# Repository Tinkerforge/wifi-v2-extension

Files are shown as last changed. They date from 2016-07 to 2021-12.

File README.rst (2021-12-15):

WIFI Extension 2.0
==================

This repository contains the hardware design files.
The software is included in the Master Brick software
and can be found at https://github.com/Tinkerforge/master-brick

Repository Content
------------------

hardware/:
 * Contains KiCad project files and additionally schematics as PDF

datasheets/:
 * Contains datasheets for sensors and complex ICs that are used

Hardware
--------

The hardware is designed with the open source EDA Suite KiCad
(http://www.kicad.org). Before you are able to open the files,
you have to install the Tinkerforge kicad-libraries
(https://github.com/Tinkerforge/kicad-libraries). You can either clone
them directly in hardware/ or clone them in a separate folder and
symlink them into hardware/
(ln -s kicad_path/kicad-libraries project_path/hardware). After that you
can open the .pro file in hardware/ with KiCad and from there view and
modify the schematics and the PCB layout.

Toolchain
---------

Clone and build toolchain from https://github.com/pfalcon/esp-open-sdk
into toolchain/ directory. The following instructions apply for ESP8266 SDK 1.5.3::

 sudo apt-get install build-essential gperf libtool libtool-bin help2man texinfo libncurses5-dev python2.7-dev autoconf
 mkdir toolchain
 cd toolchain
 git clone --recursive https://github.com/Tinkerforge/esp-open-sdk.git
 cd esp-open-sdk
 make STANDALONE=y VENDOR_SDK=1.5.3

Update toolchain::

 make clean
 git pull
 git submodule sync
 git submodule update
 make STANDALONE=y VENDOR_SDK=1.5.3

Additionally we use libesphttpd::

 cd toolchain
 git clone --recursive http://git.spritesserver.nl/libesphttpd.git/

To be able to build the extension firmware using libesphttpd a patch must be
applied to the ESP8266 SDK. This assumes that the toolchain is already
successfully built::

 cd software
 patch -b -N -d ../toolchain/esp-open-sdk/sdk/include -p1 < esp8266sdk-c_types.patch

libesphttpd must also be patched::

 cd software
 patch -b -N -d ../toolchain/libesphttpd -p1 < libesphttpd-Makefile.patch
 patch -b -N -d ../toolchain/libesphttpd -p1 < libesphttpd-httpd-nonos.patch

Build
-----

Provided that all the steps of the toolchain section was followed properly the
extension firmware can be built with::

 cd software
 make clean
 make

The compiled firmware can be found here::

 software/firmware/wifi_extension_v2_firmware.zbin

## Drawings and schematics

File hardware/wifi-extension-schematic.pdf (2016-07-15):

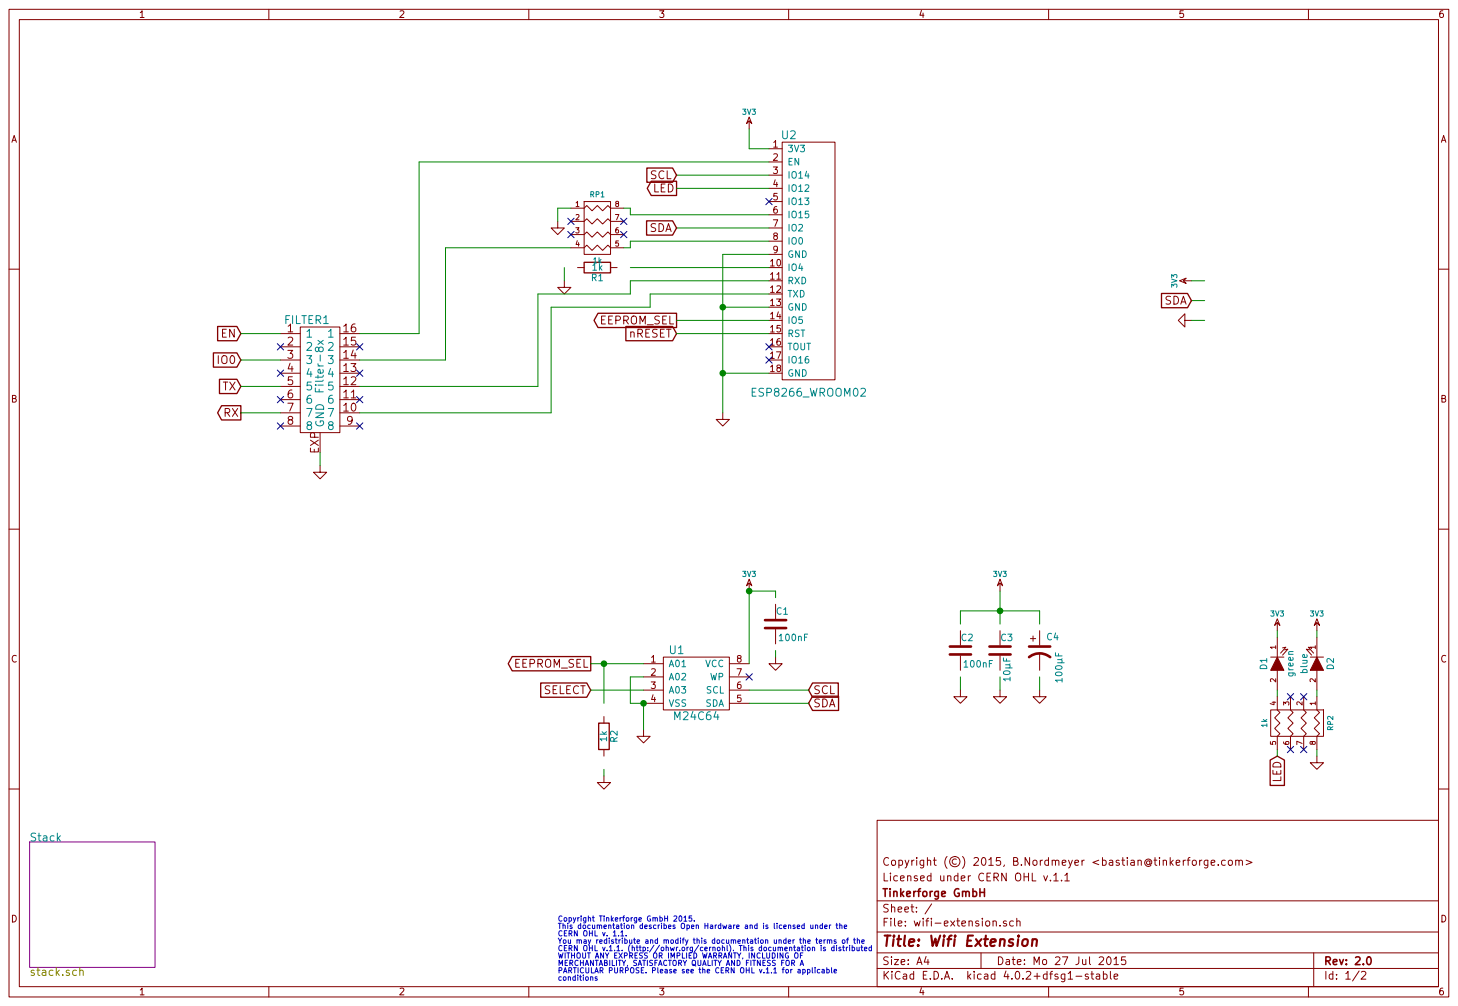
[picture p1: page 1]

File: wifi-extension.sch Sheet: / Tinkerforge GmbH

Copyright Tinkerforge GmbH 2015. This documentation describes Open Hardware and is licensed under the CERN OHL v. 1.1. You may redistribute and modify this documentation under the terms of the CERN OHL v.1.1. (http://ohwr.org/cernohl). This documentation is distributed WITHOUT ANY EXPRESS OR IMPLIED WARRANTY, INCLUDING OF MERCHANTABILITY, SATISFACTORY QUALITY AND FITNESS FOR A

Id: 1/2 Title: Wifi Extension

PARTICULAR PURPOSE. Please see the CERN OHL v.1.1 for applicable
conditions

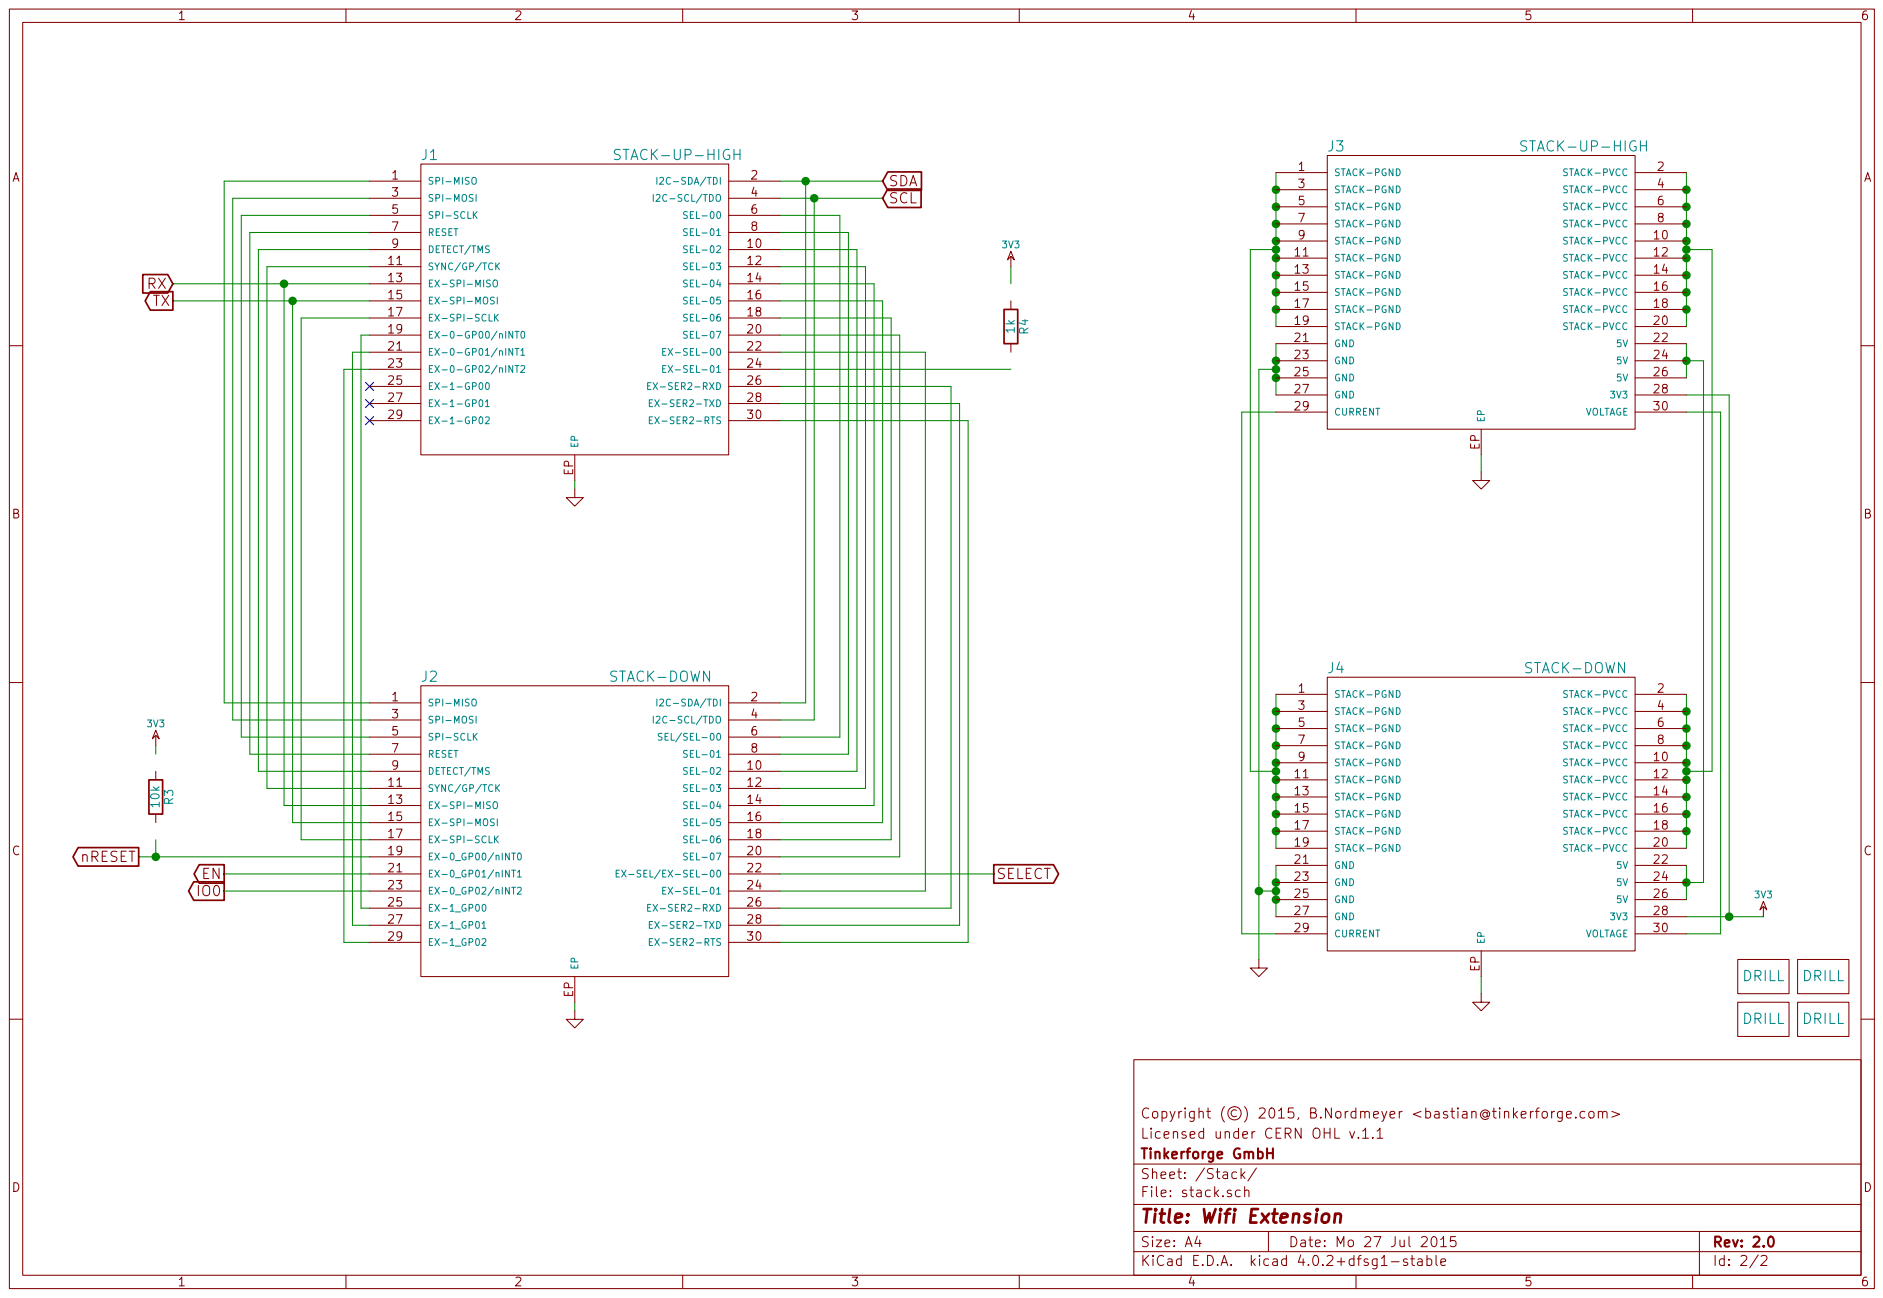
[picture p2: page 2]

SPI-MOSI 3
SPI-SCLK 5

Licensed under CERN OHL v.1.1 Copyright (©) 2015, B.Nordmeyer <bastian@tinkerforge.com> EN

File: stack.sch Sheet: /Stack/ Tinkerforge GmbH

Id: 2/2 Title: Wifi Extension

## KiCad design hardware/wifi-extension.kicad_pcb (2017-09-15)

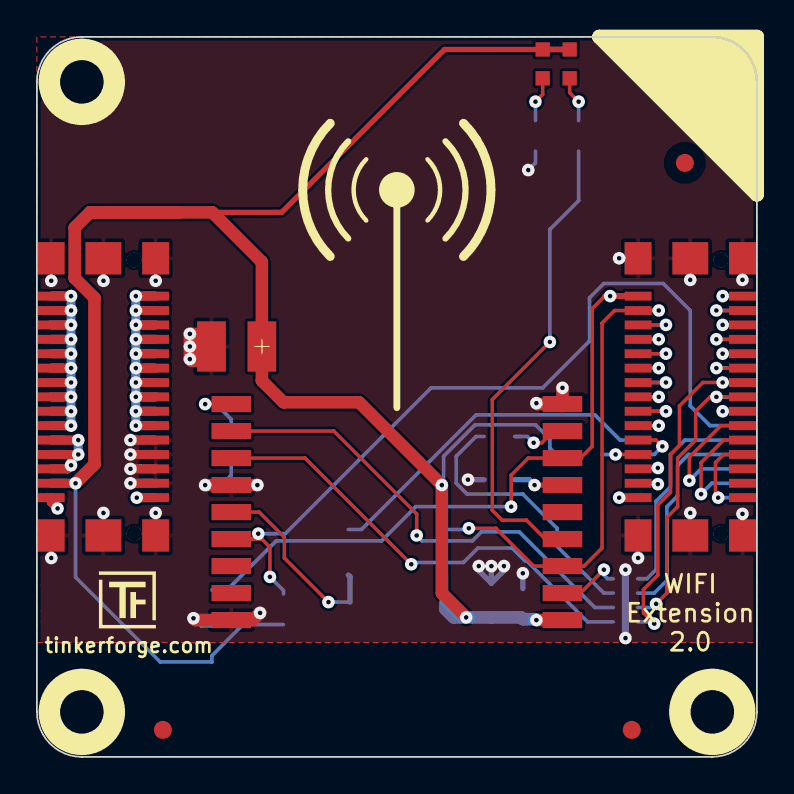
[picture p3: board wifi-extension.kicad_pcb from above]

Board: 2 copper layers, 40.0 x 40.0 mm, 34 parts (0 on the bottom side), 49 nets.

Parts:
C1, C2: 100nF; C0603E
C3: 10µF; C0805E
C4: 100µF; 3528-21
D1: green; D0603
D2: blue; D0603
FILTER1: Filter-8x; DFN16-33x135
Fiducial_Mark: VAL**; Fiducial_Mark
Fiducial_Mark#2, Fiducial_Mark#3, Fiducial_Mark#4, Fiducial_Mark#5, Fiducial_Mark#6: VAL**; Fiducial_Mark
J1, J3: STACK-UP-HIGH; BTB08-ACS-TOP
J2, J4: STACK-DOWN; BTB08-ACS-BTM
P1, P2, P3: CONN_1; TSTPT
R1, R2, R4: 1k; R0603E
R3: 10k; R0603E
RP1, RP2: 1k; 0603X4
U1: M24C64; SOIC8
U2: ESP8266_WROOM02
U3, U4, U5, U6: DRILL; DRILL_NP
VAL: CE_5mm
VAL#2: WEEE_7mm_back

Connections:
3V3: C1.2, C2.2, C3.2, C4.1, D1.1, D2.1, J3.28, J4.28, P1.1, R3.1, R4.1, U1.8, U2.1
EEPROM_SEL: R2.1, U1.1, U2.14
EN: FILTER1.1, J2.21
GND: C1.1, C2.1, C3.1, C4.2, FILTER1.EXP, J1.EP, J2.EP, J3.21, J3.23, J3.25, J3.27, J3.EP, J4.21, J4.23, J4.25, J4.27, J4.EP, P3.1, R1.2, R2.2, RP1.1, RP2.8, U1.2, U1.4, U2.9, U2.13, U2.18
IO0: FILTER1.3, J2.23
LED: RP2.5, U2.4
unnamed: D1.2, RP2.4
unnamed: D2.2, RP2.1
unnamed: FILTER1.10, U2.12
unnamed: FILTER1.12, U2.11
unnamed: FILTER1.14, RP1.4
unnamed: FILTER1.16, U2.2
unnamed: J1.1, J2.1
unnamed: J1.3, J2.3
unnamed: J1.5, J2.5
unnamed: J1.6, J2.6
unnamed: J1.7, J2.7
unnamed: J1.8, J2.8
unnamed: J1.9, J2.9
unnamed: J1.10, J2.10
unnamed: J1.11, J2.11
unnamed: J1.12, J2.12
unnamed: J1.14, J2.14
unnamed: J1.16, J2.16
unnamed: J1.17, J2.17
unnamed: J1.18, J2.18
unnamed: J1.19, J2.25
unnamed: J1.20, J2.20
unnamed: J1.21, J2.27
unnamed: J1.22, J2.24
unnamed: J1.23, J2.29
unnamed: J1.24, R4.2
unnamed: J1.26, J2.26
unnamed: J1.28, J2.28
unnamed: J1.30, J2.30
unnamed: J3.1, J3.3, J3.5, J3.7, J3.9, J3.11, J3.13, J3.15, J3.17, J3.19, J4.1, J4.3, J4.5, J4.7, J4.9, J4.11, J4.13, J4.15, J4.17, J4.19
unnamed: J3.2, J3.4, J3.6, J3.8, J3.10, J3.12, J3.14, J3.16, J3.18, J3.20, J4.2, J4.4, J4.6, J4.8, J4.10, J4.12, J4.14, J4.16, J4.18, J4.20
unnamed: J3.22, J3.24, J3.26, J4.22, J4.24, J4.26
unnamed: J3.29, J4.29
unnamed: J3.30, J4.30
unnamed: R1.1, U2.10
unnamed: RP1.5, U2.8
unnamed: RP1.8, U2.6
RX: FILTER1.7, J1.13, J2.13
SCL: J1.4, J2.4, U1.6, U2.3
SDA: J1.2, J2.2, P2.1, U1.5, U2.7
SELECT: J2.22, U1.3
TX: FILTER1.5, J1.15, J2.15
nRESET: J2.19, R3.2, U2.15

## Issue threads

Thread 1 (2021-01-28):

Status LED does not turn back on, when manually turned off and back on

PatrickBaus, 2021-01-28:
Hi,

I am working with the WIFI 2.0 extension and during testing I found what seems to be a bug in the status led handling.

When the wifi module is in client mode the green status led is lit, when connected. Now if I turn is off using the [BrickMaster.disable_wifi2_status_led()](https://www.tinkerforge.com/en/doc/Software/Bricks/Master_Brick_Python.html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) call it turn off as it is supposed to, but when I enable the led using [BrickMaster.enable_wifi2_status_led()](https://www.tinkerforge.com/en/doc/Software/Bricks/Master_Brick_Python.html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), it will stay off. I glanced at the source code and if you run [enable_wifi2_status_led()](https://www.tinkerforge.com/en/doc/Software/Bricks/Master_Brick_Python.html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)/FunctionID 99, the wifi extensions seems to register with some event system. So if there is no new event, the led will stay off.

**Expected behaviour**: The led turns back on
**As is**: The led is only turned back on, if there is an internal event, that switches the led.
**Master firmware**: 2.4.10
**WIFI 2.0 firmware**: 2.1.4

Closed 2021-12-15.

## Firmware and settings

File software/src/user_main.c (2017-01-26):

/* WIFI Extension 2.0
 * Copyright (C) 2015 Olaf Lüke <olaf@tinkerforge.com>
 * Copyright (C) 2016 Ishraq Ibne Ashraf <ishraq@tinkerforge.com>
 *
 * user_main.c: Handling of communication between PC and WIFI Extension
 *
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
 * You should have received a copy of the GNU Lesser General Public
 * License along with this library; if not, write to the
 * Free Software Foundation, Inc., 59 Temple Place - Suite 330,
 * Boston, MA 02111-1307, USA.
 */

#include "espmissingincludes.h"
#include "osapi.h"
#include "gpio.h"
#include "user_interface.h"
#include "drivers/uart.h"
#include "tfp_connection.h"
#include "http_connection.h"
#include "tfp_websocket_connection.h"
#include "uart_connection.h"
#include "debug.h"
#include "i2c_master.h"
#include "eeprom.h"
#include "logging.h"
#include "configuration.h"
#include "espconn.h"
#include "ringbuffer.h"
#include <string.h>
#include <esp8266.h>

extern Ringbuffer tfp_rb;
extern Configuration configuration_current;
extern Configuration configuration_current_to_save;
extern uint8_t tfp_rb_buffer[TFP_RING_BUFFER_SIZE];

void ICACHE_FLASH_ATTR user_init_done_cb(void) {
	char str_fw_version[4];

	os_bzero(str_fw_version, sizeof(str_fw_version));
	configuration_apply_post_init();

	if(!configuration_current.mesh_enable) {
		tfp_open_connection();
		tfpw_open_connection();

		os_sprintf(str_fw_version, "%d%d%d", FIRMWARE_VERSION_MAJOR, FIRMWARE_VERSION_MINOR,
			FIRMWARE_VERSION_REVISION);

		if(strtoul(str_fw_version, NULL, 10) >= 204) {
			if(configuration_current.general_website == 1) {
				http_open_connection();
			}
		}
		else {
			if(configuration_current.general_website_port > 1) {
				http_open_connection();
			}
		}
	}
}

void ICACHE_FLASH_ATTR user_init() {
	#ifdef DEBUG_ENABLED
		debug_enable(UART_DEBUG);
	#else
		system_set_os_print(0);
	#endif

	logd("user_init()\n");

	gpio_init();

	wifi_status_led_install(12, PERIPHS_IO_MUX_MTDI_U, FUNC_GPIO12);

	#ifdef DEBUG_ENABLED
		configuration_use_default();
	#else
		i2c_master_init();
		eeprom_init();
		configuration_load_from_eeprom();
	#endif

	// The documentation says we can not call station_connect and similar
	// in user_init, so we do it in the callback after it is done!
	configuration_apply_during_init();

	// We want to make UART communication to the master of the stack ready ASAP.
	ringbuffer_init(&tfp_rb, tfp_rb_buffer, TFP_RING_BUFFER_SIZE);
	uart_con_init();
	brickd_init();
	com_init();

	os_bzero(&configuration_current_to_save, sizeof(configuration_current));
	os_memcpy(&configuration_current_to_save, &configuration_current, sizeof(configuration_current));

	system_init_done_cb(user_init_done_cb);
}

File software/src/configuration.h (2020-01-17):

/* WIFI Extension 2.0
 * Copyright (C) 2015 Olaf Lüke <olaf@tinkerforge.com>
 * Copyright (C) 2016 Ishraq Ibne Ashraf <ishraq@tinkerforge.com>
 * Copyright (C) 2020 Matthias Bolte <matthias@tinkerforge.com>
 *
 * configuration.h: WIFI Extension configuration handling
 *
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
 * You should have received a copy of the GNU Lesser General Public
 * License along with this library; if not, write to the
 * Free Software Foundation, Inc., 59 Temple Place - Suite 330,
 * Boston, MA 02111-1307, USA.
 */

#ifndef CONFIGURATION_H
#define CONFIGURATION_H

#include "config.h"
#include "c_types.h"
#include "mesh.h"

#define CONFIGURATION_EXPECTED_VERSION 2

#define CONFIGURATION_ADDRESS 32

#define CONFIGURATION_SECRET_MAX_LENGTH 64
#define CONFIGURATION_HOSTNAME_MAX_LENGTH 32
#define CONFIGURATION_PASSWORD_MAX_LENGTH 64
#define CONFIGURATION_SSID_MAX_LENGTH 32
#define CONFIGURATION_AP_PASSWORD_MIN_LENGTH 8

typedef struct {
	// Configuration info
	uint8_t  conf_checksum;
	uint8_t  conf_version;
	uint16_t conf_length;

	// General configuration
	uint16_t general_port;
	uint16_t general_websocket_port;
	uint16_t general_website_port;
	uint8_t  general_phy_mode;
	uint8_t  general_sleep_mode;
	uint8_t  general_website;
	char     general_authentication_secret[CONFIGURATION_SECRET_MAX_LENGTH]; // might not be NULL-terminated

	// Client configuration
	bool     client_enable;
	char     client_ssid[CONFIGURATION_SSID_MAX_LENGTH]; // might not be NULL-terminated
	uint8_t  client_ip[4];
	uint8_t  client_subnet_mask[4];
	uint8_t  client_gateway[4];
	uint8_t  client_mac_address[6];
	uint8_t  client_bssid[6];
	char     client_hostname[CONFIGURATION_HOSTNAME_MAX_LENGTH]; // might not be NULL-terminated
	char     client_password[CONFIGURATION_PASSWORD_MAX_LENGTH]; // might not be NULL-terminated

	// AP configuration
	bool     ap_enable;
	char     ap_ssid[CONFIGURATION_SSID_MAX_LENGTH]; // might not be NULL-terminated
	uint8_t  ap_ip[4];
	uint8_t  ap_subnet_mask[4];
	uint8_t  ap_gateway[4];
	uint8_t  ap_encryption;
	bool     ap_hidden;
	uint8_t  ap_mac_address[6];
	uint8_t  ap_channel;
	char     ap_hostname[CONFIGURATION_HOSTNAME_MAX_LENGTH]; // might not be NULL-terminated
	char     ap_password[CONFIGURATION_PASSWORD_MAX_LENGTH]; // might not be NULL-terminated

	// Mesh configuration
	bool     mesh_enable;
	char     mesh_router_ssid[CONFIGURATION_SSID_MAX_LENGTH]; // might not be NULL-terminated
	char     mesh_router_password[CONFIGURATION_PASSWORD_MAX_LENGTH]; // might not be NULL-terminated
	uint8_t  mesh_root_ip[4];
	uint8_t  mesh_root_subnet_mask[4];
	uint8_t  mesh_root_gateway[4];
	uint8_t  mesh_router_bssid[6];
	char     mesh_group_ssid_prefix[(CONFIGURATION_SSID_MAX_LENGTH / 2)]; // might not be NULL-terminated
	char     mesh_password[CONFIGURATION_PASSWORD_MAX_LENGTH]; // might not be NULL-terminated
	uint8_t  mesh_group_id[ESP_MESH_GROUP_ID_LEN];
	char     mesh_gateway_hostname[32]; // Currently unused.
	uint8_t  mesh_gateway_ip[4];
	uint16_t mesh_gateway_port;
} Configuration;

void ICACHE_FLASH_ATTR configuration_use_default(void);
void ICACHE_FLASH_ATTR configuration_load_from_eeprom(void);
uint8_t ICACHE_FLASH_ATTR configuration_save_to_eeprom(void);
void ICACHE_FLASH_ATTR configuration_apply_during_init(void);
void ICACHE_FLASH_ATTR configuration_apply_post_init(void);
void ICACHE_FLASH_ATTR configuration_init(void);
void ICACHE_FLASH_ATTR configuration_apply_tf_mesh(void);

#endif

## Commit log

2015-07-27 first draft of wifi 2.0 prototype
    [stack.sch, wifi-extension.kicad_pcb, wifi-extension.sch]
2015-07-27 prototype finished
    [stack.sch, wifi-extension.kicad_pcb, wifi-extension.sch]
2015-08-07 change schematic description of 2. page
    [stack.sch]
2015-08-13 change rx/tx interface to extension SPI interface
    [stack.sch, wifi-extension.kicad_pcb, wifi-extension.sch]
2015-08-21 fix flash interface
    [wifi-extension.kicad_pcb, wifi-extension.sch]
2015-09-07 Add initial (pre-cleanup) version of WIFI 2.0 code
    This is a "rapid-prototype" that still needs major cleanup
    and restructuring. The UART protocol implementation seems
    to be working and stable, so we can always compare a cleaned up
    version to this commit.
2015-09-11 remove signal switch, new esp8266 signal connections
    [stack.sch, wifi-extension.kicad_pcb, wifi-extension.sch]
2015-09-22 Add I2C, EEPROM, brickd, authentication
    [configuration.h]
2015-09-25 Update documentation
    [0D-ESP8266__Pin_List__Release_15-11-2014.xlsx]
2015-09-25 fully routed
    [stack.sch, wifi-extension.kicad_pcb, wifi-extension.sch]
2015-09-28 Add status getter implementation
    [configuration.h]
2015-10-14 updated schematic
    [stack.sch, wifi-extension.sch]
2015-10-14 ordered prototype
    [wifi-extension.kicad_pcb]
2015-10-26 remove antenna symbol, move ce and weee logo
    [wifi-extension.kicad_pcb]
2015-11-10 add filter, change silkscreen
    [stack.sch, wifi-extension.kicad_pcb, wifi-extension.sch]
2016-02-24 ordered version
    [wifi-extension.kicad_pcb]
2016-02-24 uncomitted changes
    [wifi-extension.kicad_pcb]
2016-06-10 Add status led api
2016-07-15 add missing schematic
2016-07-30 Apply input filter for inputs that should only have hexadecimal values
2016-09-10 Highlight submit buttons
2016-09-23 Fix authenticate button logic
2016-09-30 Consistent handling of WiFi PHY mode and AP encryption between brickv and the web interface
    [configuration.h]
2016-10-07 Fix typos
    [configuration.h]
2016-10-07 Fix maximum lengths and application of AP and general password settings
    [configuration.h]
2016-10-13 Fix handling of potentially non-NUL-terminated strings
    [configuration.h]
2016-10-17 Fix typo and data type
    [user_main.c]
2016-10-24 Make sure station_connection is never called from inside user_init
    [configuration.h]
2016-11-03 Fix to be able to access EEPROM when debug is on
    [communication.c, communication.h, eeprom.c]
2016-11-03 Restructured mesh test implementation
    [configuration.h]
2016-11-04 Get rid of flash mode switching hack
2016-11-11 Print payload also as a string
2016-11-11 Track and print total connected clients
2016-11-11 No need to track connected clients. Remove unused function
2016-11-15 New config struct for mesh
    [configuration.h]
2016-11-18 Cleanup configuration apply logic, read configuration from new configuration struct print mesh related status info on system init done callback
    [configuration.h]
2016-11-18 Revert to previous non EEPROM config read when debug enabled mechanism
    [eeprom.c, user_main.c]
2016-11-18 Bring back fix to access EEPROM regardless of whether debug is turned on or off. The WiFi station connection problem seems to be introduced by the 6 libraries that are used from ESP mesh git reposito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
    [eeprom.c, user_main.c]
2016-11-19 Update c_types.h patch for SDK 1.5.3 switch
2016-11-20 Modify debug prints
2016-11-21 Implement setter and getter for mesh configuration. Integrate the existing mesh code to proper configuration management
    [configuration.h]
2016-11-25 Handle wrong configuration state that can be caused by older brickv when being used with newer extension firmware which already had mesh mode enabled
    [communication.c]
2016-11-30 Rename config parameters, server_ip and server_port to gateway_ip and gateway_port and new currently unused parameter gateway hostname
    [configuration.h]
2016-12-12 Send buffer support which enables sending packet from previous packet's sent callback. This is the suggested way to send packets using ESP8266 SDK
    [configuration.h]
2016-12-13 Fix socket pointer issue
    [tfp_connection.c]
2017-01-03 Buffer size fix and root node ping reply feature
    [tfp_mesh_connection.h]
2017-01-03 Better way of fixing the hostname derivation problem from mesh prefix
    [configuration.h]
2017-01-03 Mesh mode router SSID maximum length fix for API calls
    [communication.h]
2017-01-04 It is better to keep the struct sizes consistent with the API argument data sizes
    [configuration.h]
2017-01-05 Configure do ping timer as a free running timer
2017-01-19 Return error if brickd function is not implemented
    [communication.c]
2017-01-19 add tfp message error codes
    [communication.h]
2017-01-19 Adapt to API naming changes
    [configuration.h]
2017-02-24 Don't try to send data if our receive buffer is full, we very likely just didn't yet parse the ACK yet in this case
    [uart_connection.c]
2017-02-24 We clear the receive buffer after a message if it was full at the start of the state machine (the next message is likely broken)
    [uart_connection.c]
2017-02-24 Add send check and write finish prototypes
2017-02-24 Don't call brickd_disconnect directly in disconnect callback. We may still get a message back from the Master that then can be routed correctly and thrown away.
    [tfp_connection.c]
2017-02-24 Call brickd_disconnect at beginning of connect callback, to remove all routes that are still there and now definitely not correct anymore
    [tfp_connection.c]
2017-02-24 Use COPY flag (finish callback) to be able to send new data even if we didn't receive an ACK. This means we can support Windows delayed ACKs more efficently
    [tfp_connection.c]
2017-02-24 Move route match removal to correct position (after we tested if we can send data)
    [tfp_connection.c]
2017-02-28 Remove unnecessary current_match temporary variable
2017-09-15 Add 3d information (final)
    [stack.sch, wifi-extension.kicad_pcb, wifi-extension.sch]
2018-02-20 Cleanup KiCad libraries config
    Ensure LibDir=kicad-libraries and LibName1=tinkerforge.
    Remove special library.
2018-11-26 Fix libesphttpd patches for current version of libesphttpd
2020-01-17 Enforce minimum AP password length of 8 chars
    [configuration.h]
2020-01-17 Add missing defines for strnlen function
    [communication.c]
2021-10-25 Update KiCad link
    https://www.kicad.org/blog/2021/10/Avoid-links-to-former-kicad-domain/
2021-12-15 Workaround LED staying off in client mode after enabling the LED again
    The ESP SDK LED code seems to be fully event driven. The LED is
    constantly on in client mode if a connection is established. If the
    LED is turned off and turned on again in this state then it will
    stay off. Because the ESP SDK LED code doesn't seem to restore the
    LED state to the expected state on re-registering the LED with the
    SDK logic.
    Workaround this by turning the LED on before registering it to the
    SDK logic. This ensures the LED will be on in client mode. This
    also works correctly if the SDK logic lets the LED blink. The only
    case where this will result in the wrong LED state is when the LED
    should actually be of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
    [communication.c]
2021-12-17 Avoid crash when using mesh functions in non-mesh mode
    Closes #2.
    [communication.c]
